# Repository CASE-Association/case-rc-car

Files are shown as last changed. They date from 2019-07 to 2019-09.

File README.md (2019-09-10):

# CASE RC Car
Control a rc car wirelessly by tilting your hand!

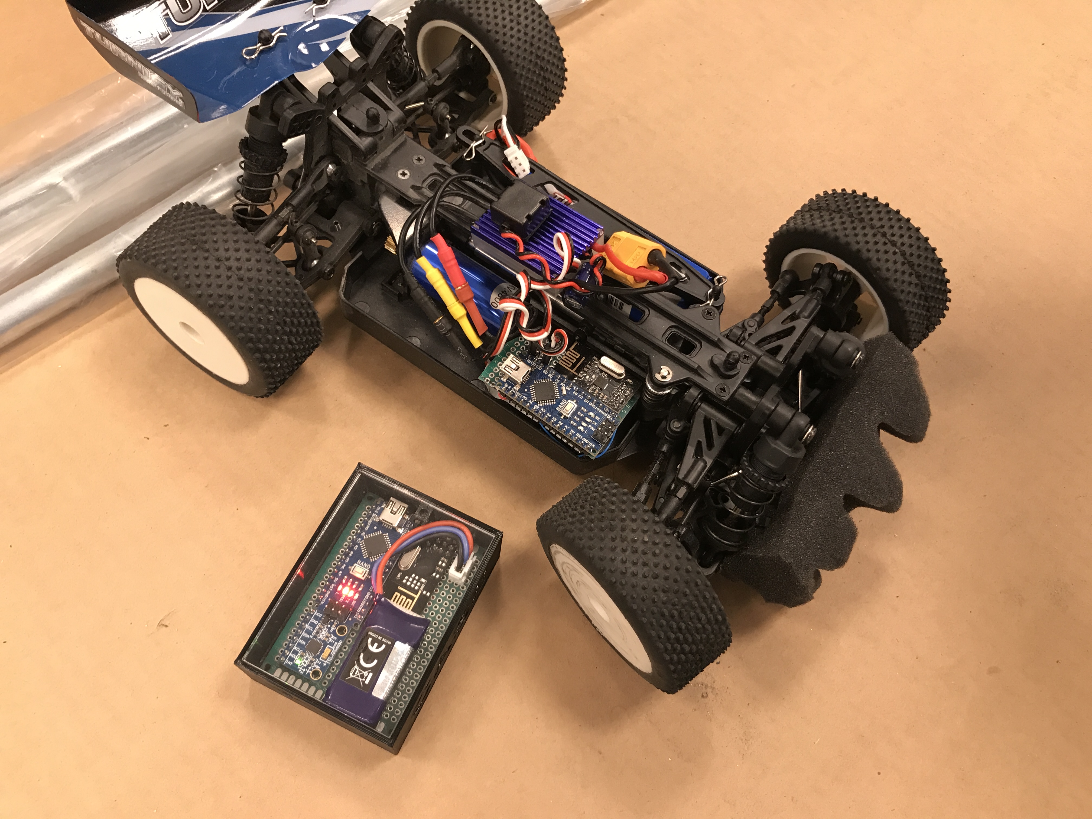
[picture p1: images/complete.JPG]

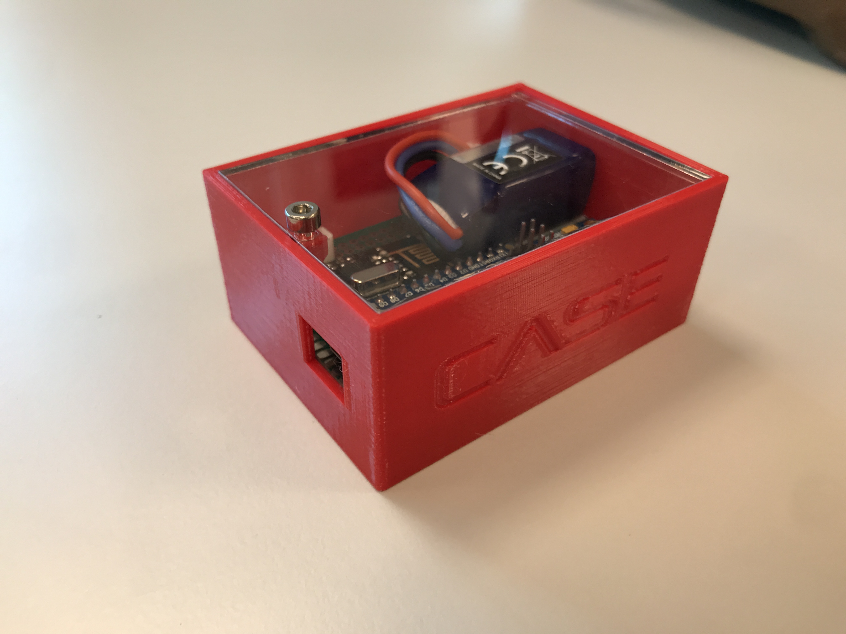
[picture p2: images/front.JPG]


## System overview
The system consist of 2 main parts, the RC car with a reciever module and a transmitter module.

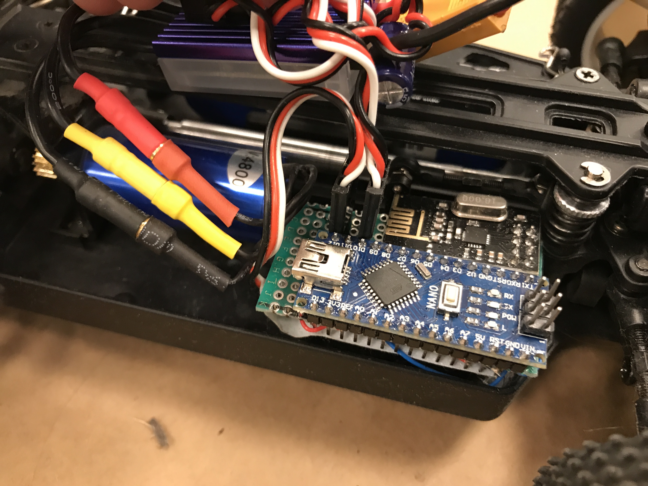
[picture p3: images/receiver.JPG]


The reciever module is an Arduino Nano, NRF24L01+ (wireless transceiver) and 2x3 pin headers on a perfboard. It connects to the ESC and Servo via the two pin headers. The ESC supplies 5V to the Arduino and the Servo. The Arduino supplies control signals to the ESC and the Servo.

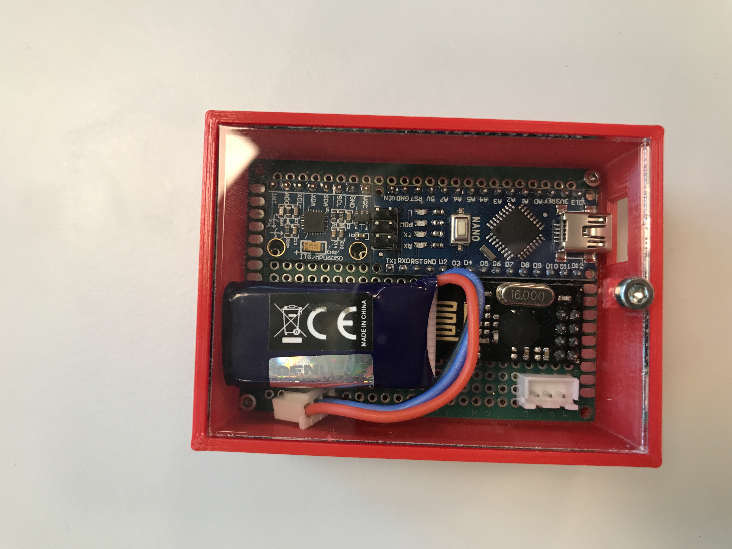
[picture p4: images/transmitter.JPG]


The transmitter module consists of a Arduino nano, NRF24L01+, MPU6050 (IMU, accelerometer + gyroscope) a voltage regulator (buck) on a perfboard inside a 3D printed case with a acrylic panel on top. 

## How do you use it?
<b>Step 1</b>

Connect both ESC and Servo to the reciever perfboard on the rc car.
Connect a 2s LiPo battery to the rc car and power it on.
The car should beep a few times and then turn the wheels to a forward drive and stand still.

<b>Step 2</b>

Strap the transmitter box on top of your hand with the veclro strap.

Turn on transmitter by plugging in the battery in the JST connector.

Place your hand so that your palm faces, the MCU will start talking with the IMU, setting it up and calibrating.

After about 3s the system is ready and you can tilt your hand to control the car.

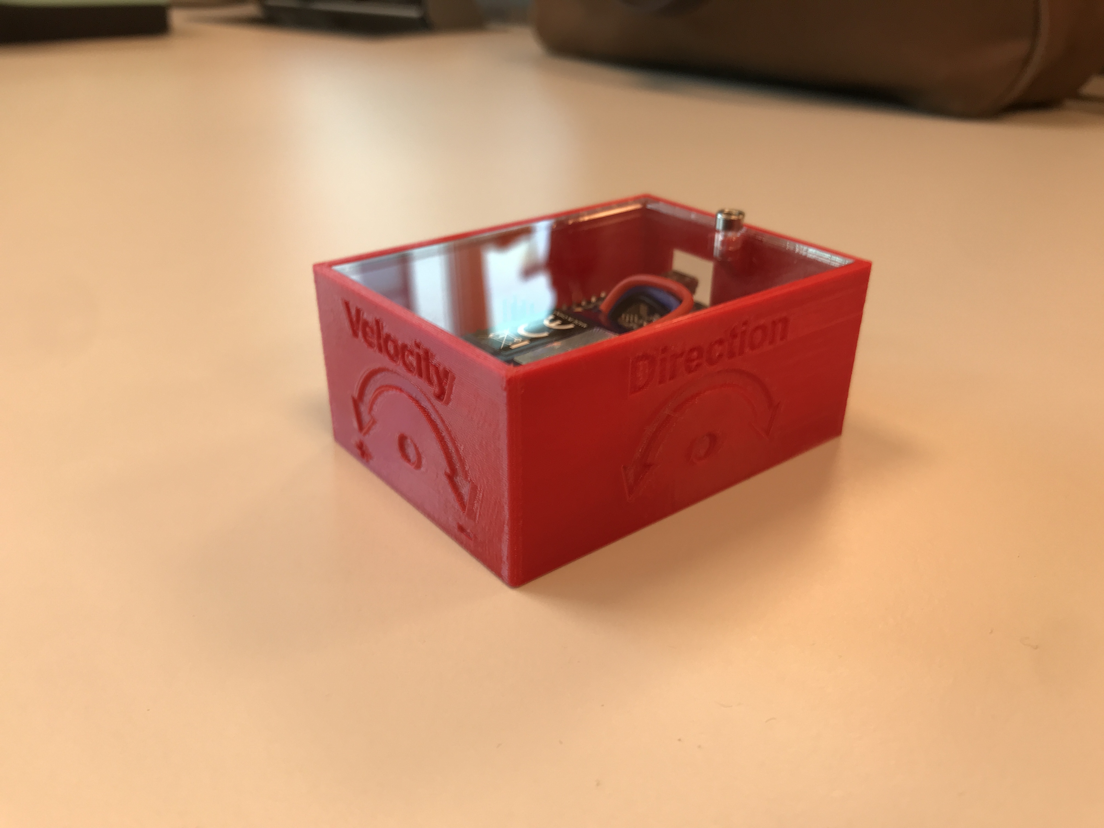
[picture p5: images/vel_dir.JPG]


Tilt your hand forward to accelerate and backwards to decelerate. In order to reverse you have to go to normal position, backwards, then normal and then backwards again.

Tilt your hand to the right or left to turn. 

## How does it work?
We use the gravity vector on X and Y axis to determine how to accelerate/decelerate and turn.
Take a look at the code (it has alot of comments) if you are interested to see the inner workings. 

## Creating more
The files for the box and panel are in the hardware folder. (STL, STEP, F3D, DXF)

## Development
The plattformio project contains personal VS code tasks for uploading and monitoring both devices with a single button click. 
You will have to edit them for them to work on your system.

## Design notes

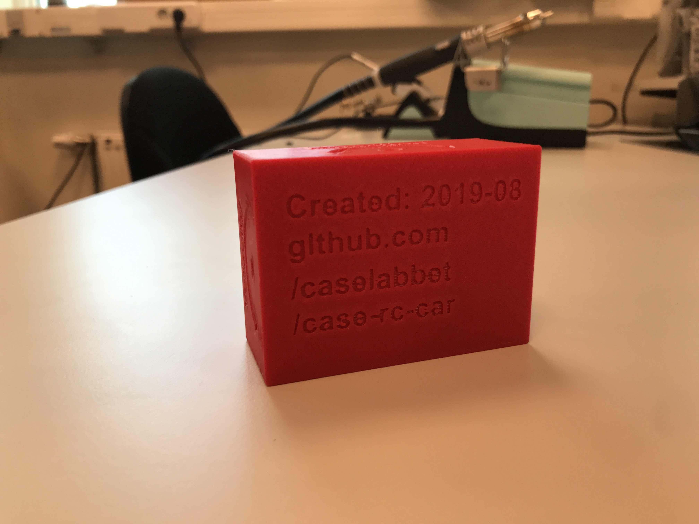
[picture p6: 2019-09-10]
images/bottom.JPG

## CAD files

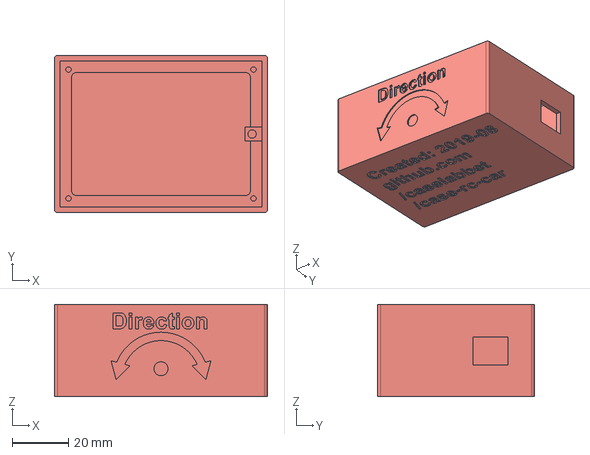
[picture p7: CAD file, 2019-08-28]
hardware/Box.step
76.0 x 56.0 x 33.0 mm

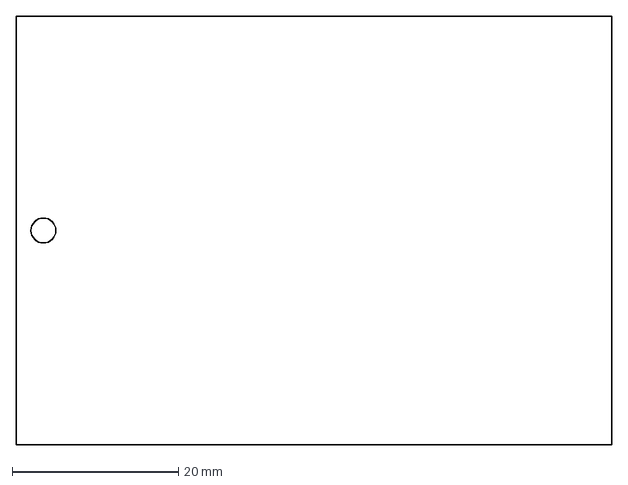
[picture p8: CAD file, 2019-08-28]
hardware/acrylic_panel.dxf
71.5 x 51.5 mm

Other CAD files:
hardware/Box.f3d
hardware/box.stl

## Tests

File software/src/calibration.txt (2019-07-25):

Initializing I2C devices...
Testing device connections...
MPU6050 connection successful
PID tuning Each Dot = 100 readings
............
at 600 Readings

//                X Accel  Y Accel  Z Accel   X Gyro   Y Gyro   Z Gyro
//#define OFFSETS    822,    1116,    1172,     148,      68,      37

..700 Total Readings

//                X Accel  Y Accel  Z Accel   X Gyro   Y Gyro   Z Gyro
//#define OFFSETS    826,    1122,    1178,     148,      71,      29

..800 Total Readings

//                X Accel  Y Accel  Z Accel   X Gyro   Y Gyro   Z Gyro
//#define OFFSETS    828,    1126,    1182,     149,      73,      40

..900 Total Readings

//                X Accel  Y Accel  Z Accel   X Gyro   Y Gyro   Z Gyro
//#define OFFSETS    830,    1128,    1184,     148,      75,      30

..1000 Total Readings

//                X Accel  Y Accel  Z Accel   X Gyro   Y Gyro   Z Gyro
//#define OFFSETS    830,    1128,    1184,     149,      76,      33

 Any of the above offsets will work nice

 Lets proof the PID tuning using another method:
averaging 1000 readings each time
expanding:
....    XAccel                  YAccel                          ZAccel                  XGyro                   YGyro                   ZGyro
 [0,0] --> [-7686,-7684]        [0,0] --> [-10843,-10840]       [0,0] --> [5275,5274]   [0,0] --> [-591,-593]   [0,0] --> [-274,-273]   [0,0] --> [-132,-134]
.... [0,1000] --> [-7684,1568]  [0,1000] --> [-10845,-1217]     [0,1000] --> [5273,14650]       [0,1000] --> [-594,3404]        [0,1000] --> [-272,3724]        [0,1000] --> [-133,3862]
.... [0,1000] --> [-7684,1566]  [0,2000] --> [-10842,8407]      [0,2000] --> [5274,24022]       [0,1000] --> [-591,3404]        [0,1000] --> [-269,3724]        [0,1000] --> [-130,3861]

closing in:
..      XAccel                  YAccel                          ZAccel                  XGyro                   YGyro                   ZGyro
 [500,1000] --> [-3058,1566]    [1000,2000] --> [-1215,8407]    [1000,2000] --> [14646,24022]   [0,500] --> [-591,1407] [0,500] --> [-269,1730] [0,500] --> [-130,1868]
.. [750,1000] --> [-745,1566]   [1000,1500] --> [-1215,3595]    [1000,1500] --> [14646,19337]   [0,250] --> [-591,406]  [0,250] --> [-269,728]  [0,250] --> [-130,868]
.. [750,875] --> [-745,402]     [1000,1250] --> [-1215,1193]    [1000,1250] --> [14646,16993]   [125,250] --> [-93,406] [0,125] --> [-269,228]  [0,125] --> [-130,368]
.. [812,875] --> [-173,402]     [1125,1250] --> [-25,1193]      [1125,1250] --> [15811,16993]   [125,187] --> [-93,155] [62,125] --> [-23,228]  [0,62] --> [-130,115]
.. [812,843] --> [-173,104]     [1125,1187] --> [-25,570]       [1125,1187] --> [15811,16392]   [125,156] --> [-93,30]  [62,93] --> [-23,100]   [31,62] --> [-8,115]
..      XAccel                  YAccel                          ZAccel                  XGyro                   YGyro                   ZGyro
 [827,843] --> [-42,104]        [1125,1156] --> [-25,284]       [1156,1187] --> [16108,16392]   [140,156] --> [-34,30]  [62,77] --> [-23,36]    [31,46] --> [-8,50]
.. [827,835] --> [-42,32]       [1125,1140] --> [-25,131]       [1171,1187] --> [16243,16392]   [148,156] --> [-1,30]   [62,69] --> [-23,4]     [31,38] --> [-8,20]
.. [831,835] --> [-1,32]        [1125,1132] --> [-25,52]        [1179,1187] --> [16321,16392]   [148,152] --> [-1,14]   [65,69] --> [-11,4]     [31,34] --> [-8,2]
.. [831,833] --> [-1,13]        [1125,1128] --> [-25,12]        [1183,1187] --> [16353,16392]   [148,150] --> [-1,6]    [67,69] --> [-3,4]      [32,34] --> [-4,2]
averaging 10000 readings each time
.................... [831,832] --> [-1,17]      [1126,1128] --> [-2,12] [1185,1187] --> [16371,16392]   [148,149] --> [-1,2]    [68,69] --> [0,4]       [33,34] --> [-1,2]
....................    XAccel                  YAccel                          ZAccel                  XGyro                   YGyro                   ZGyro
 [831,832] --> [-2,17]  [1127,1128] --> [0,12]  [1185,1186] --> [16371,16389]   [148,149] --> [0,2]     [68,69] --> [0,4]       [33,34] --> [0,2]
.................... [831,832] --> [-1,17]      [1127,1128] --> [0,12]  [1185,1186] --> [16369,16389]   [148,149] --> [0,2]     [68,68] --> [0,1]       [33,34] --> [0,2]
-------------- done --------------

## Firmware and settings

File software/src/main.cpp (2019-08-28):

/**
 * @file main.cpp
 * @author Isak Åslund (aslundisak@gmail.com)
 * @brief Wirelessly controlled  RC car by tilting your hand. Uses an Arduino (MCU), MPU6050 (IMU) and NRF24 (wireless transceiver)
 * @comment This code is heavily inspired and dependant on the I2Cdev and MPU6050 library from jrowberg. Check it out on github.
 * @links https://github.com/jrowberg/i2cdevlib and https://github.com/jrowberg/i2cdevlib/tree/master/Arduino/MPU6050 
 * @version 0.1
 * @date 2019-08-28
 */

// ================================================================
// ===                     Includes                             ===
// ================================================================
#include <Arduino.h>
#include <SPI.h>
#include <Servo.h>
#include <math.h>
#include "RF24.h"
#include "I2Cdev.h"
#include "MPU6050_6Axis_MotionApps20.h"  
#include "Wire.h"

// ================================================================
// ===                      Defines                             ===
// ================================================================
//#define TRANSMITTER     // Uncommet for trasmitter, comment for receiver.
#define DEBUG             // Deactivating serial print greatly increases the responsiveness of the system.

#define INTERRUPT_PIN   2 // Used for MPU6050 data ready interrupt
#define TURN_PIN        3 // PWM pin for servo controlling turning
#define THROTTLE_PIN    5 // PWM pin for ESC controlling speed

// ================================================================
// ===                     Global variables                     ===
// ================================================================

// Since the ESC and servo expects servo PWM signals which is 20ms apart and between 1-2ms long
// it can be hard to use normal PWM signal that's why we use the servo library. 
Servo servo;
Servo ESC;

// NRF24
RF24 radio(7, 8);                   // 7 - CE, 8 -CSN
const byte address[6] = "00001";    // Adress for communicating
unsigned long lastData = 0;         // Used for knowing if data has been received recently
typedef struct{
    int throttle;
    int turn;
}message_t;                         // Struct for making sending/receiving easy
message_t msg; 

// MPU6050
int16_t ax, ay, az;     // Acceleration X, Y, Z
int16_t gx, gy, gz;     // Gyro values X, Y, Z
int lastValue;          // Used for creating a low pass filter for turning angle
MPU6050 mpu;

// MPU control/status vars
bool dmpReady = false;  // set true if DMP init was successful
uint8_t mpuIntStatus;   // holds actual interrupt status byte from MPU
uint8_t devStatus;      // return status after each device operation (0 = success, !0 = error)
uint16_t packetSize;    // expected DMP packet size (default is 42 bytes)
uint16_t fifoCount;     // count of all bytes currently in FIFO
uint8_t fifoBuffer[64]; // FIFO storage buffer

// orientation/motion vars
Quaternion q;           // [w, x, y, z]         quaternion container
VectorInt16 aa;         // [x, y, z]            accel sensor measurements
VectorInt16 aaReal;     // [x, y, z]            gravity-free accel sensor measurements
VectorInt16 aaWorld;    // [x, y, z]            world-frame accel sensor measurements
VectorFloat gravity;    // [x, y, z]            gravity vector
float euler[3];         // [psi, theta, phi]    Euler angle container
float ypr[3];           // [yaw, pitch, roll]   yaw/pitch/roll container and gravity vector

// ================================================================
// ===               INTERRUPT DETECTION ROUTINE                ===
// ================================================================

volatile bool mpuInterrupt = false;     // indicates whether MPU interrupt pin has gone high
void dmpDataReady() {
    mpuInterrupt = true;
}

// ================================================================
// ===                      INITIAL SETUP                       ===
// ================================================================

void setup() {
    Wire.begin();
    Wire.setClock(400000); // 400kHz I2C clock

    Serial.begin(9600);

    Serial.println("=============================================================")
    Serial.println("----- Welcome to CASE rf car controller by jazzy hands! -----");
    Serial.print("----- This device is a: ");
    

    #ifdef TRANSMITTER
        Serial.println("TRANSMITTER -----");

        // Setup NRF24 as transmitter
        radio.begin();
        radio.openWritingPipe(address);
        radio.setPALevel(RF24_PA_MAX); 
        radio.setDataRate(RF24_2MBPS);
        radio.stopListening();

        // Initialize MPU
        Serial.println(F("Initializing MPU..."));
        mpu.initialize();
        pinMode(INTERRUPT_PIN, INPUT);

        // Verify connection
        Serial.println(F("Testing MPU connections..."));
        Serial.println(mpu.testConnection() ? F("MPU6050 connection successful") : F("MPU6050 connection failed"));

        // Load and configure the DMP
        Serial.println(F("Initializing DMP on MPU..."));
        devStatus = mpu.dmpInitialize();

        // Calibration data
        // see calibration.txt for more info. 
        mpu.setXGyroOffset(148);
        mpu.setYGyroOffset(68);
        mpu.setZGyroOffset(33);
        mpu.setZAccelOffset(1185);

        // make sure it worked (returns 0 if so)
        if (devStatus == 0) {
            // Calibration Time: generate offsets and calibrate our MPU6050
            mpu.CalibrateAccel(6);
            mpu.CalibrateGyro(6);
            mpu.PrintActiveOffsets();
            Serial.println(F("Enabling DMP..."));
            mpu.setDMPEnabled(true);

            // enable Arduino interrupt detection
            Serial.print(F("Enabling interrupt detection (Arduino external interrupt "));
            Serial.print(digitalPinToInterrupt(INTERRUPT_PIN));
            Serial.println(F(")..."));
            attachInterrupt(digitalPinToInterrupt(INTERRUPT_PIN), dmpDataReady, RISING);
            mpuIntStatus = mpu.getIntStatus();

            // set our DMP Ready flag so the main loop() function knows it's okay to use it
            Serial.println(F("DMP ready and running!"));
            dmpReady = true;

            // get expected DMP packet size for later comparison
            packetSize = mpu.dmpGetFIFOPacketSize();
        } else {
            // ERROR!
            // 1 = initial memory load failed
            // 2 = DMP configuration updates failed
            // (if it's going to break, usually the code will be 1)
            Serial.print(F("DMP Initialization failed (code "));
            Serial.print(devStatus);
            Serial.println(F(")"));
        }
    #else
        Serial.println("RECIEVER -----");

        // 1-2ms where 1.5ms is 90deg on servo and no throttle on ESC
        servo.attach(TURN_PIN, 1000, 2000);
        ESC.attach(THROTTLE_PIN, 1000, 2000);

        // Setup as receiver
        radio.begin();
        radio.openReadingPipe(0, address);
        radio.setPALevel(RF24_PA_MAX);
        radio.setDataRate(RF24_2MBPS);
        radio.startListening();
    #endif
}



// ================================================================
// ===                    MAIN PROGRAM LOOP                     ===
// ================================================================

void loop() {
    #ifdef TRANSMITTER
        // if programming failed, don't try to do anything
        if (!dmpReady) return;

        // wait for MPU interrupt or extra packet(s) available
        while (!mpuInterrupt && fifoCount < packetSize) {
            if (mpuInterrupt && fifoCount < packetSize) {
            // try to get out of the infinite loop 
            fifoCount = mpu.getFIFOCount();
            }  
            // other program behavior stuff here
        }

        // reset interrupt flag and get INT_STATUS byte
        mpuInterrupt = false;
        mpuIntStatus = mpu.getIntStatus();

        // get current FIFO count
        fifoCount = mpu.getFIFOCount();
        if(fifoCount < packetSize){
                //Lets go back and wait for another interrupt. We shouldn't be here, we got an interrupt from another event
                // This is blocking so don't do it   while (fifoCount < packetSize) fifoCount = mpu.getFIFOCount();
        }
        // check for overflow (this should never happen unless our code is too inefficient)
        else if ((mpuIntStatus & _BV(MPU6050_INTERRUPT_FIFO_OFLOW_BIT)) || fifoCount >= 1024) {
            // reset so we can continue cleanly
            mpu.resetFIFO();
            //  fifoCount = mpu.getFIFOCount();  // will be zero after reset no need to ask
            Serial.println(F("FIFO overflow!"));

        // otherwise, check for DMP data ready interrupt (this should happen frequently)
        } else if (mpuIntStatus & _BV(MPU6050_INTERRUPT_DMP_INT_BIT)) {

            // read a packet from FIFO
            while(fifoCount >= packetSize){ 
    
                mpu.getFIFOBytes(fifoBuffer, packetSize);
                // track FIFO count here in case there is > 1 packet available
                // (this lets us immediately read more without waiting for an interrupt)
                fifoCount -= packetSize;
            }

        // Get raw motion data
        mpu.getMotion6(&ax, &ay, &az, &gx, &gy, &gz);
        // We use gravity vector on X and Y axis to determine how to accelerate/decelerate and turn.
        // This makes it possible to walk around in a room and rotate your entire body without affecting which way turns where.
        // You will know what I mean if you try and use absolute orientation angles.

        // The RC car is extremly fast (40+ km/h )
        // We have to map the accelerometer value from min/max to servo signal (0-180) and scale it to reduce max speed 
        // A accelerometer value of 0 means no acceleration and should map to 90 which means no throttle. 0 is full reverse and 180 full forward.
        msg.throttle = map(ax, -17000, 17000, 80, 110);
        // The ESC has slower backward speed than forward so we inscrease the speed backwards to make it easier to use.
        if(msg.throttle < 88){
            msg.throttle = msg.throttle / 2;
        }

        // We want the full motion for turning so we only map the acceleration value to a value form 0-180 where 0 maps to 90 (no turn)
        msg.turn = map(ay, -17000, 17000, 0, 180);
        // We apply a crude low pass filter on the turn signal to reduce vibrations in the servo.
        msg.turn = 0.8 * msg.turn + 0.2 * lastValue;
        lastValue = msg.turn;

        #ifdef DEBUG
            Serial.print("Data - ax, ay\t");
            Serial.print( msg.throttle );
            Serial.print("\t");
            Serial.println( msg.turn );
        #endif

        // Send the data
        radio.write(&msg, sizeof(msg));        
        }
    #else  // Receiver
        if (radio.available()) {
            // Read and store the data in the struct. 
            message_t data; 
            radio.read(&data, sizeof(data));

            #ifdef DEBUG
            Serial.print("RECIEVED - throttle, turn:\t");
            Serial.print(data.throttle);
            Serial.print("\t");
            Serial.println(data.turn);
            #endif

            // The Receiver does no processing of data
            // This makes it possible to only update the transmitter when updating code, neat! :) 
            servo.write( data.turn );
            ESC.write( data.throttle );

            // Udate that we got data
            lastData = millis();
        }else{
            //If there hasn't been data for 200ms (something went wrong or transmitter power off), send default values to the car and stop it.
            if(millis() - lastData > 200){
                servo.write(90);
                ESC.write(90);
            }
        }
    #endif
}
